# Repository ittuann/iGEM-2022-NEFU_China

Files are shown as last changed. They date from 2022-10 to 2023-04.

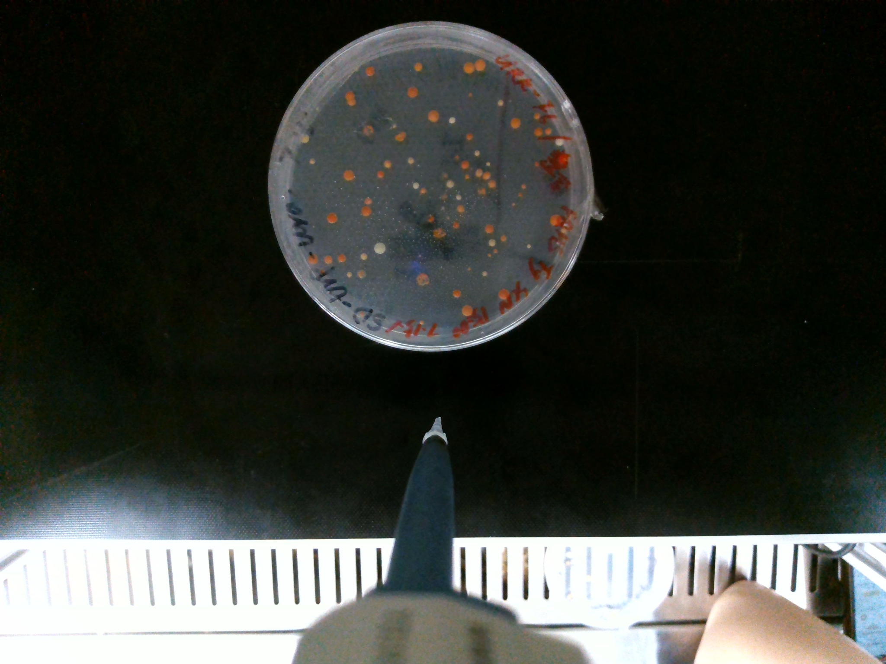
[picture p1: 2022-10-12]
Code/Visual Identification Module/10.jpg

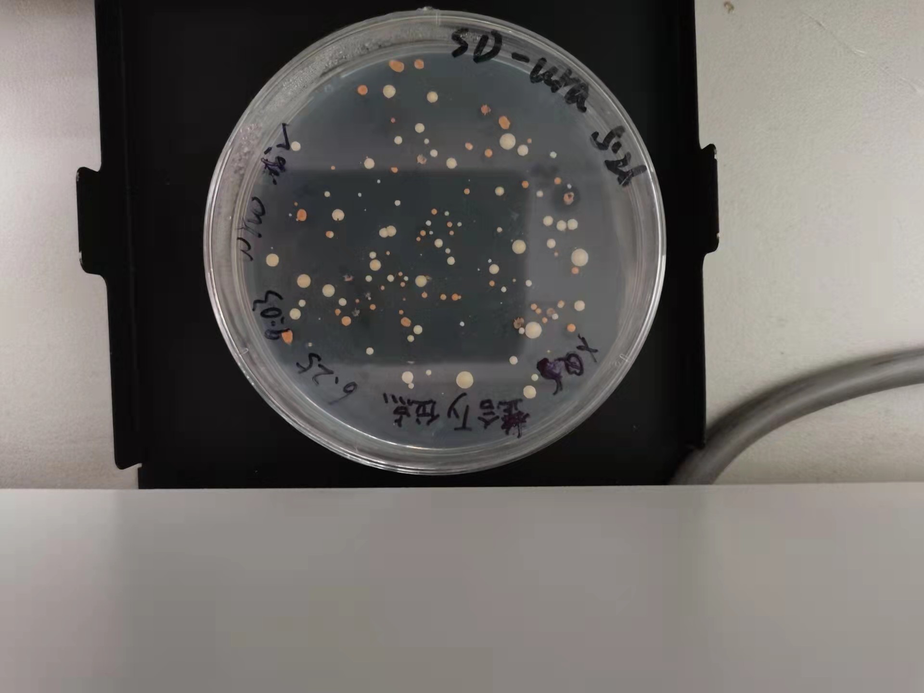
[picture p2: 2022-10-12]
Code/Visual Identification Module/1.jpg

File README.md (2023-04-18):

<div style="text-align:center;">
    <a href="https://2022.igem.wiki/nefu-china/index">
        iGEM NEFU-China
    </a>
</div>

# iGEM 2022 NEFU_China Open Project

This is iGEM team NEFU_China 2022 GitHub Repository.

Detailed information about this project can be found on our **[Wiki Website](https://2022.igem.wiki/nefu-china/hardware)**: <https://2022.igem.wiki/nefu-china/hardware>

## Repository Directory Structure

Under each folder exists a README.md document, which can be viewed for more information.

- **Code**

  Contains all project code for our four modules. (Pipette Module, Frame Module, Robotic Arm Module, Visual Identification Module)

- **Model**

  Contains all the hardware 3D models we have created (in STL format), and the complete SolidWorks project that used to create these models.

- **PCB**

  Contains two PCB projects that we designed using Altium Designer.

- **Document**

  Contains operation document for our hardware.

## License

Look at each project to find out which LICENSE it is using.

## Contacts

For any questions, feel free to contact me via email ittuann@outlook.com

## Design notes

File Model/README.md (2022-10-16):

# iGEM 2022 NEFU_China Open Project

This folder contains  all the 3D hardware models we have created (in STL format), and the complete SolidWorks project that used to create these models.

## 3D model in STL format

We have released four module independent 3D models in STL format. They are `Frame Module.STL`, `Pipette Module.STL`, `Robotic Arm Module.STL` and `Visual Identification Module.STL`.

We also released two complete 3D models of the hardware. `Hardware.STL` is the full version, `Hardware Lite.STL` is the lightweight version without the robot arm module.

The STL format is a widely used 3D model format. Most of the systems have built-in software to view the STL format. When you have downloaded the model, you can view it directly on your computer.

## Project 

We open source the entire project for designing and making 3D models. 

It requires specialized software SolidWorks 2021 to open.

With this open project, you can view every detail of our design, and modify the model as needed to use it in your work environment.

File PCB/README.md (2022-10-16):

# iGEM 2022 NEFU_China Open Project

We open source the entire project for the design and fabrication of our two PCB boards.

It requires the special software Altium Designer 2021 to open it.

With this open project, you can view every detail of our design and modify it as needed to use it in your working environment.

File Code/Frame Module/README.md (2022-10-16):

# iGEM 2022 NEFU_China Open Project

We use code from the open source project Marlin in this section. You can check this link to access that open source project https://github.com/MarlinFirmware/Marlin

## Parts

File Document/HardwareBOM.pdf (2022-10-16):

Serial number | Name | Specification | Amount | Unit price | Total cost
1 | 8mm optical shaft | 398mm，X-axis | 2 | 6.05/m | 4.92
2 | | 334mm，Y-axis | 2 | 6.05/m | 4.92
3 | | 390mm，Z-axis | 4 | 6.05/m | 9.84
4 | Extended flange linear bearings | LMF8LUU 8*15*45 | 4 | 3.16 | 12.65
5 | Longer linear bearings | LM8LUU 8*15*45 | 4 | 1.07 | 4.29
6 | Aluminium profiles (Euro 2020) | 450mm，X-axis | 4 | 1.6863/ m | 3.37
7 | | 340mm，Y-axis | 4 | 1.6863/ m | 2.53
8 | | 390mm，Z-axis | 4 | 1.6863/ m | 2.95
9 | Aluminium profiles (Euro 1010) | 467mm, hot bed | 2 | 1.602/m | 1.55
10 | Corner Code | 2020 / 2028 | 20 | 0.18 | 3.60
11 | Profile nuts | Euro 20 type M4 | 100 | 0.02 | 1.85
12 | | Euro 20 type M5 | 100 | 0.02 | 1.85

13 | Stepper motors | 2.54MM | 5 | 2.81 | 14.05
14 | Limit switches | 1A125V | 4 | 0.14 | 0.56
15 | Motor drives | A4988 | 4 | 2.53 | 10.12
16 | Heat sink | | 5 | 0.14 | 0.70
17 | T8 Screws | lead 8-350mm | 2 | 1.52 | 3.03
18 | Clearance nuts | lead 8mm | 2 | 0.98 | 1.97
19 | Stepper motor brackets | | 2 | 0.56 | 1.12
20 | Hot bed springs | | 4 | 0.11 | 0.45
21 | Nuts | | 6 | 0.06 | 0.38
22 | Limit Springs | 0.5*5*40 | 2 | 0.63 | 1.26
23 | Flexible couplings | 5×8 Flexible couplings | 2 | 0.21 | 0.42
24 | Thermistors | | 2 | 0.29 | 0.58
25 | Synchronous pulleys | 2GT 20 teeth 5mm bore and 6mm width | 2 | 1.41 | 2.81

26 | Timing belts | 2GT 6mm 2m/strip | 2 | 1.12 | 2.25
27 | Idler pulleys | Belt width 6mm 20 teeth bore 5 with teeth | 6 | 1.69 | 10.12
28 | | Belt width 6mm 20 teeth bore 5 without teeth | 2 | 1.41 | 2.81
29 | Hot bed | 200*300 | 1 | 9.55 | 9.55
30 | PE winding pipe | Inner diameter 6mm | 1 | 0.63 | 0.63
31 | Angle iron | | 12 | 0.28 | 3.37
32 | Hot bed supports | 11 gauge thickened straight sheet 40*16*2mm | 4 | 0.08 | 0.34
33 | Foot pads | 20*20*22 | 4 | 0.19 | 0.76
34 | Hexagon socket flat round head screws | M4×6 | 60 | 0.01 | 0.76
35 | | M4×8 | 12 | 0.01 | 0.17
36 | | M4×12 | 20 | 0.02 | 0.31
37 | | M4×16 | 4 | 0.02 | 0.07
38 | | M4×22 | 4 | 0.02 | 0.07
39 | | M5×8 | 40 | 0.02 | 0.84
40 | | M5×25 | 4 | 0.02 | 0.08

41 | | M5×45 | 2 | 0.04 | 0.07
42 | | M6×10 | 8 | 0.04 | 0.29
43 | Cross bolts | M2×12 | 6 | 0.01 | 0.04
44 | | M2.5×8 | 8 | 0.01 | 0.04
45 | | M3×8 | 16 | 0.01 | 0.09
46 | | M3×10 | 8 | 0.01 | 0.06
47 | | M3×14 | 44 | 0.01 | 0.37
48 | | M3×40 | 6 | 0.01 | 0.08
49 | Countersunk head screws | M3×16 | 8 | 0.01 | 0.11
50 | | M3×30 | 2 | 0.01 | 0.03
51 | Square nuts | M3*5.4*2.4 | 48 | 0.03 | 1.35
52 | Printed parts | PLA, 40% filled, 3 wall thicknesses | 1 | 7.03 | 7.03
53 | Acrylic panels | 6 large ones 7.5mm thick, 8 small ones 2mm thick | 1 | 7.87 | 7.87
54 | Touch screens | TFT24 | 1 | 19.53 | 19.53
55 | Control panels | Gen L V2.1 | 1 | 21.08 | 21.08
56 | Power supply | 12V38A | 1 | 8.15 | 8.15 | 190.093 45

1 | Visual Identification Module | 1 | 31.61 | 31.61 | 31.6125
1 | 20KG Single Shaft Servo | Brushless motors are better but more expensive | 2 | 9.13 | 18.27
2 | 35KG Single Shaft Servo | Brushless motors are better but more expensive | 1 | 12.36 | 12.36
3 | 35KG Twin Shaft Servo | Brushless motors are better but more expensive | 2 | 19.67 | 39.34
4 | Long U-bracket | | 3 | 1.48 | 4.43
5 | Short L-bracket | | 1 | 1.26 | 1.26
6 | Cup bearing | | 3 | 2.25 | 6.74
7 | Deep groove ball bearings | | 1 | 1.83 | 1.83
8 | Core plate | STM32F103C8T6 | 1 | 2.28 | 2.28
9 | Multifunctional bracket | | 4 | 1.48 | 5.90
10 | Metal rudder plate | | 5 | 2.25 | 11.24

11 | Screw nuts | 40 | 0.04 | 1.40
12 | Swivel base | 1 | 12.36 | 12.36
13 | Base counterweights | 1 | 67.44 | 67.44
14 | Base plate | 1 | 4.22 | 4.22
15 | Mechanical jaws | 1 | 11.24 | 11.24 | 200.311 25
1 | Pipette gun top cap | FDM abs 50% filled | 1 | 3.93 | 3.93
2 | Active gear for range adjustment | FDM abs 50% filled | 1 | 4.92 | 4.92
3 | Two-way cam | FDM abs 50% filled | 1 | 3.51 | 3.51
4 | 35BYJ412 motor mount | FDM abs 50% filled | 1 | 3.51 | 3.51
5 | ULN2003 stepper motor drive board | | 1 | 0.45 | 0.45
6 | 35BYJ412 motor | | 1 | 4.22 | 4.22
7 | Connection fiberglass plate | 3mm | 1 | 7.03 | 7.03
8 | Core board | STM32F103C8T6 | 1 | 2.28 | 2.28
9 | Screws | M3X22 | 2 | 0.02 | 0.04
10 | | M3X30 | 2 | 0.03 | 0.06
11 | | M3X55 | 2 | 0.03 | 0.06
12 | | M4X20 | 8 | 0.03 | 0.22

13 | M4X36 | 2 | 0.04 | 0.08 14 | Nuts | M3 | 6 | 0.01 | 0.08 15 | M4 | 10 | 0.02 | 0.21 16 | Servo connection | FDM abs 50% filled | 1 | 4.92 | 4.92 17 | Clamping piece for inner pipette gun | FDM abs 50% filled | 1 | 3.51 | 3.51 18 | Outer pipette gun clamping piece | FDM abs 50% filled | 1 | 3.51 | 3.51 19 | Inner bottom support | FDM abs 50% filled | 1 | 2.81 | 2.81 20 | Outer bottom support | FDM abs 50% filled | 1 | 2.81 | 2.81 21 | DRAGON LAB pipettes | 1 | 34.43 | 34.43 | 82.5988 Total | 504.616

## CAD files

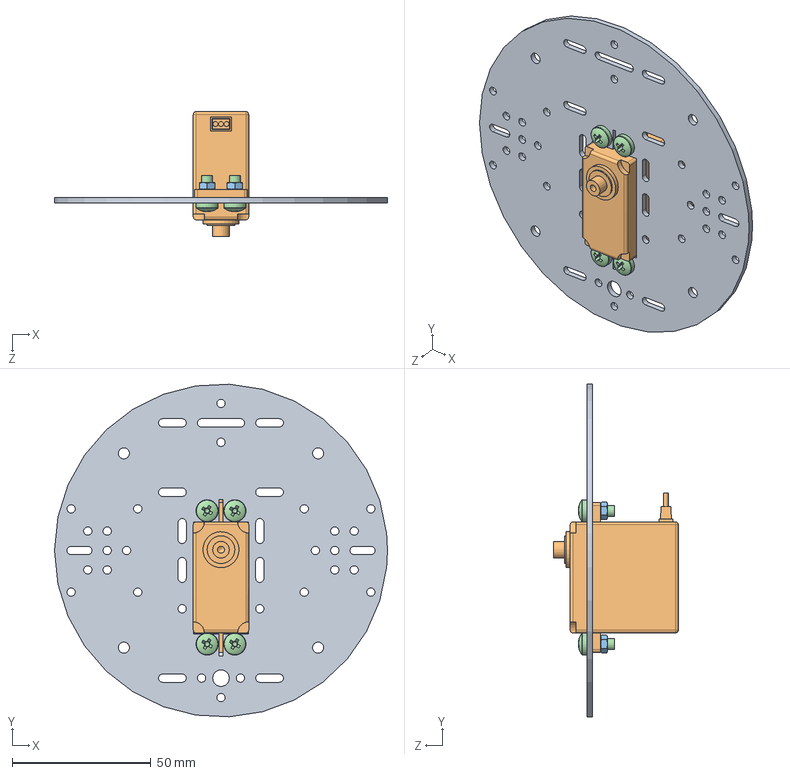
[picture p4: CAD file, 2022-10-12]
Model/Project/圆盘舵机组合.SLDASM
120.0 x 119.8 x 45.0 mm
底部圆盘
小舵机
GB6170-M4-ZN-10 x 4
GB818-M4X10-4.8 x 4

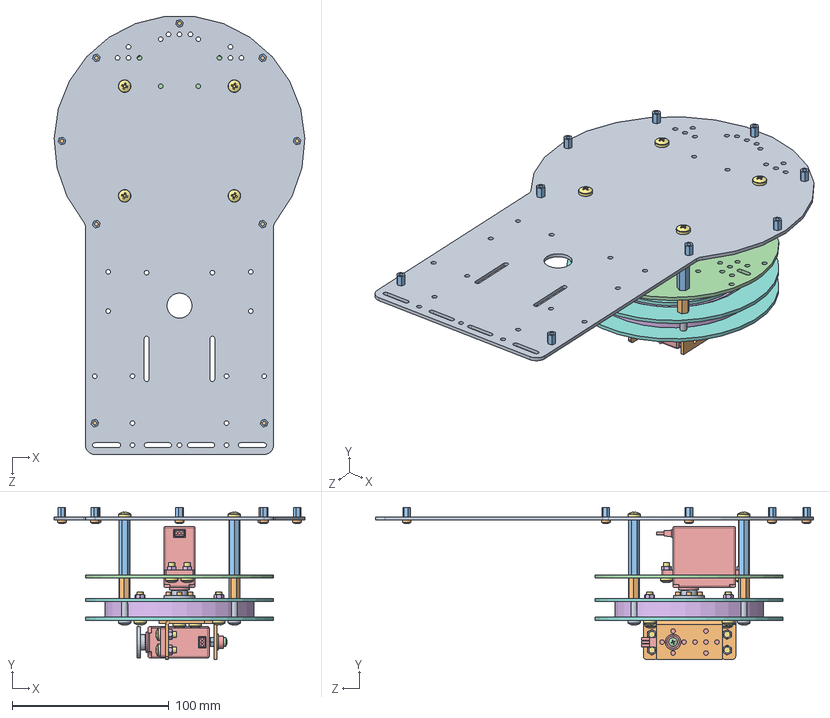
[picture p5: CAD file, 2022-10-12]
Model/Project/底座部分.SLDASM
160.0 x 97.0 x 279.4 mm
大底板
GB818-M3X6-ZN-4.8 x 13
M3X6双通铜柱 x 9
底部圆盘
小舵机 x 2
GB6170-M4-ZN-10 x 16
GB818-M4X10-4.8 x 16
小圆盘 x 2
金属舵盘 x 2
JXS006
GB6170-M3-ZN-10
GB818-M3X8-ZN-4.8
杯士轴承
大轴承
GB818-M4X18 x 4
圆环 x 2
GB818-M4X35 x 4
M4X13双通铜柱 x 4
M4X35双通铜柱 x 4

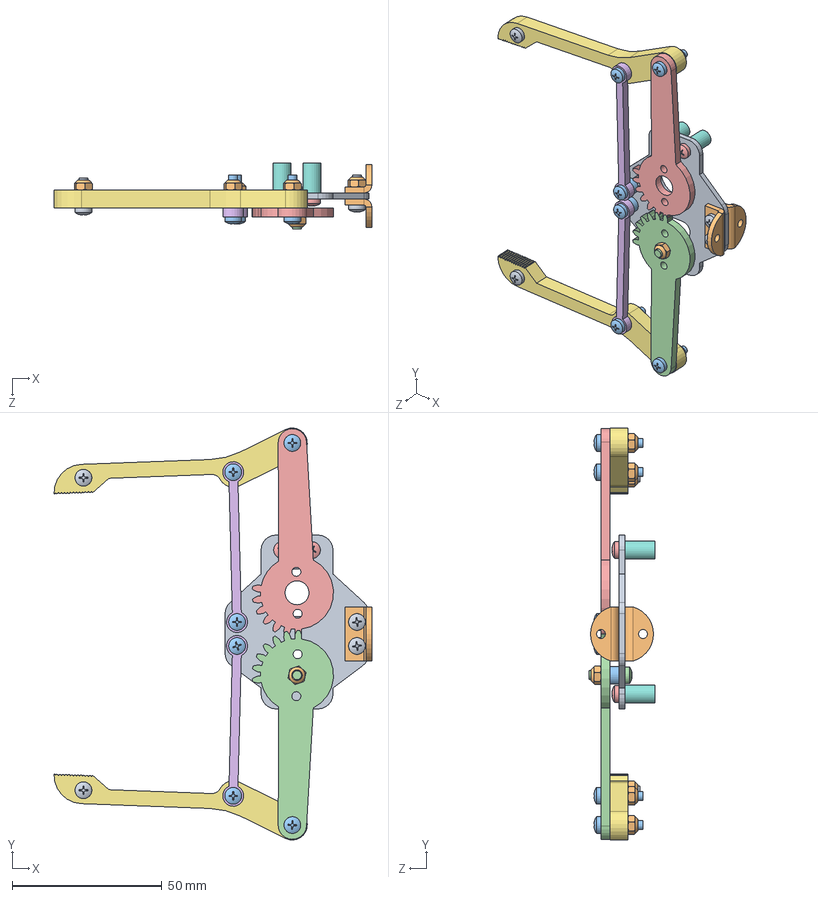
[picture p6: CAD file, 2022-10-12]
Model/Project/爪子（配合）.SLDASM
106.1 x 137.4 x 22.0 mm
手爪 （新）
安装扣 x 2
小垫片 x 3
爪子齿轮 2
爪子齿轮
小横杆 x 2
长杆 x 2
螺柱 x 4
GB818-M3X10-ZN-4.8 x 4
GB6170-M3（自锁） x 11
GB818-M3X14-ZN-4.8 x 6
GB818-M3X12-ZN-4.8
GB818-M3X6-ZN-4.8 x 4

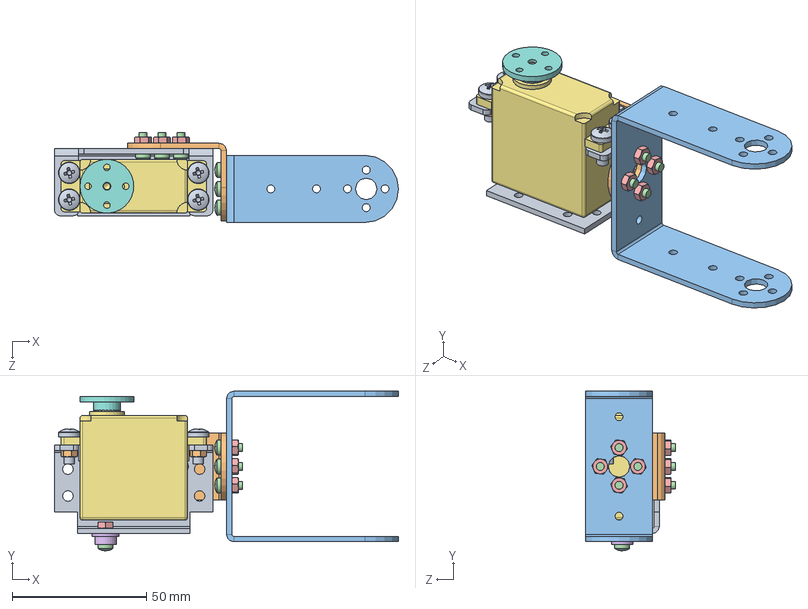
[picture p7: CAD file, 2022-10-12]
Model/Project/小臂组合（新）.SLDASM
128.0 x 59.4 x 33.5 mm
JXS006
JXS007
JXS005
GB818-M3X8-ZN-4.8 x 9
GB6170-M3-ZN-10 x 9
杯士轴承
小舵机
金属舵盘
GB818-M4X10-4.8 x 4
GB6170-M4-ZN-10 x 4

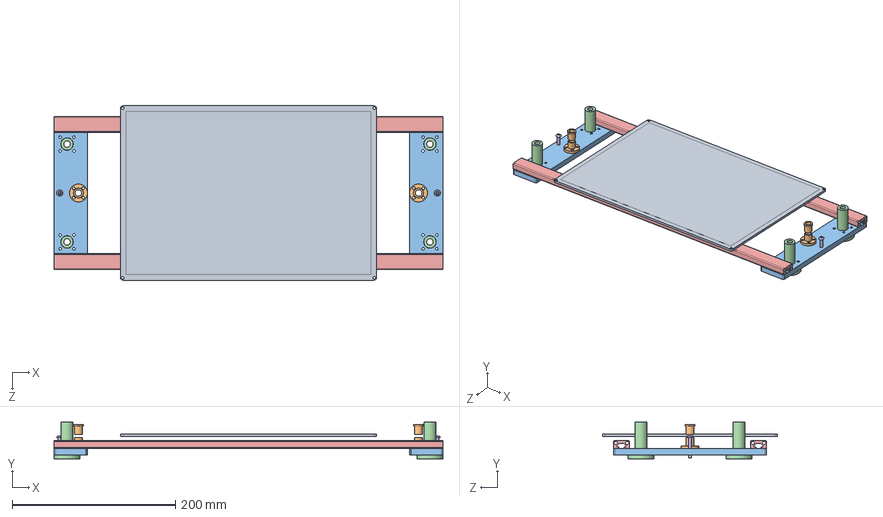
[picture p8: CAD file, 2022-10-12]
Model/Project/热床组件.SLDASM
477.0 x 45.0 x 214.0 mm
铝基板热床200×300×3
梯形螺母T8 x 2
7.5mm亚克力板 x 2
直线轴承LMF8LUU x 4
1020铝型材_热床 x 2
内六角平圆头螺钉M4×25 x 2

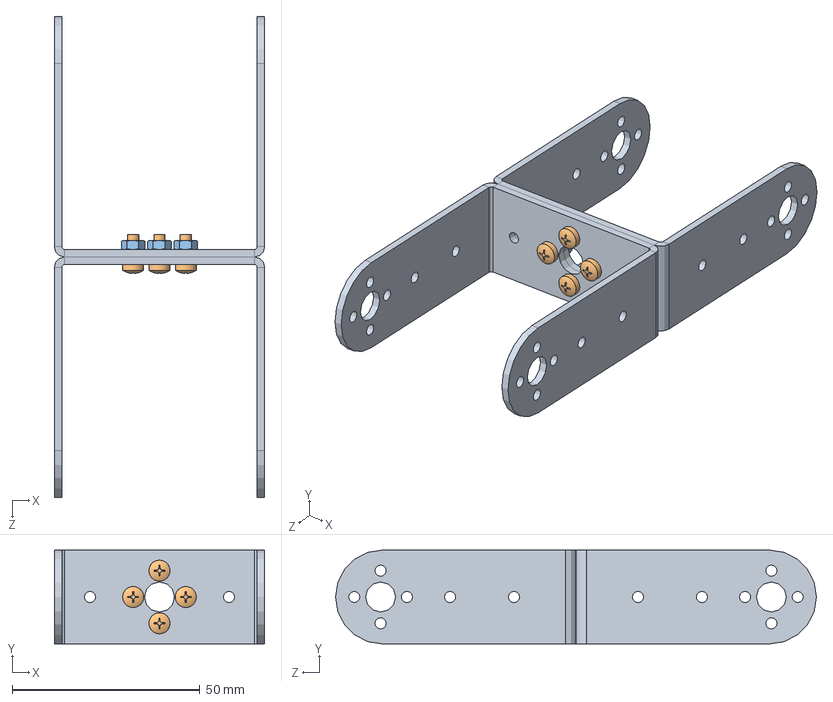
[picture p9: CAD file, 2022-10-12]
Model/Project/长臂组合.SLDASM
56.0 x 25.0 x 128.0 mm
JXS005 x 2
GB818-M3X8-ZN-4.8 x 4
GB6170-M3-ZN-10 x 4

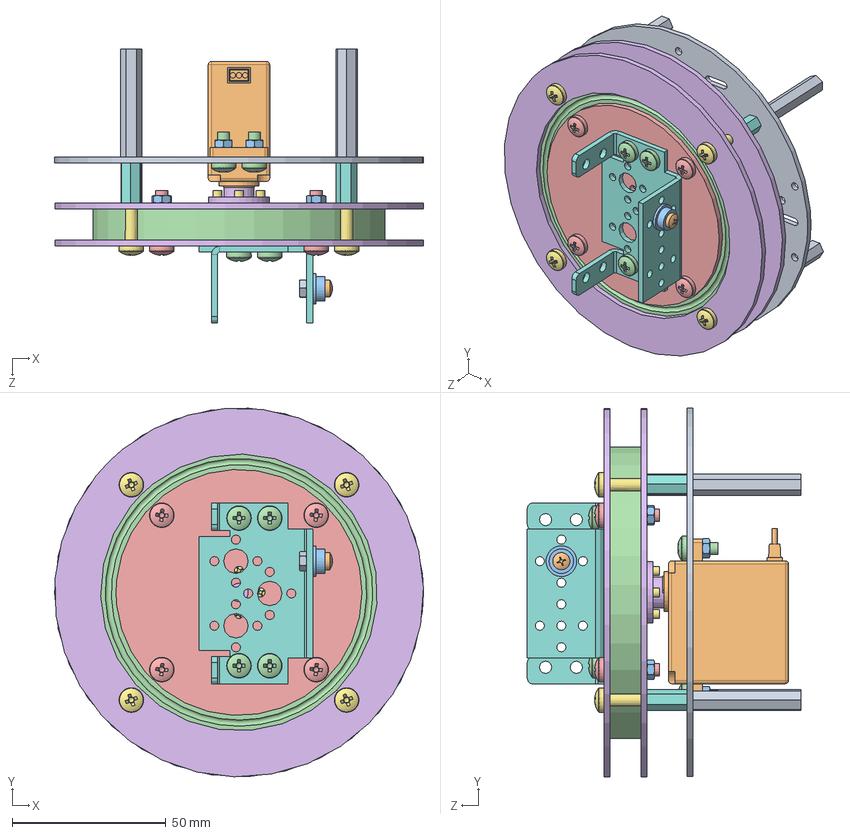
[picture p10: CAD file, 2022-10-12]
Model/Project/云台组合.SLDASM
120.0 x 119.9 x 89.0 mm
底部圆盘
小舵机
GB6170-M4-ZN-10 x 12
GB818-M4X10-4.8 x 8
小圆盘 x 2
金属舵盘
GB818-M3X6-ZN-4.8 x 4
JXS006
GB6170-M3-ZN-10
GB818-M3X8-ZN-4.8
杯士轴承
大轴承
GB818-M4X18 x 4
圆环 x 2
GB818-M4X35 x 4
M4X13双通铜柱 x 4
M4X35双通铜柱 x 4

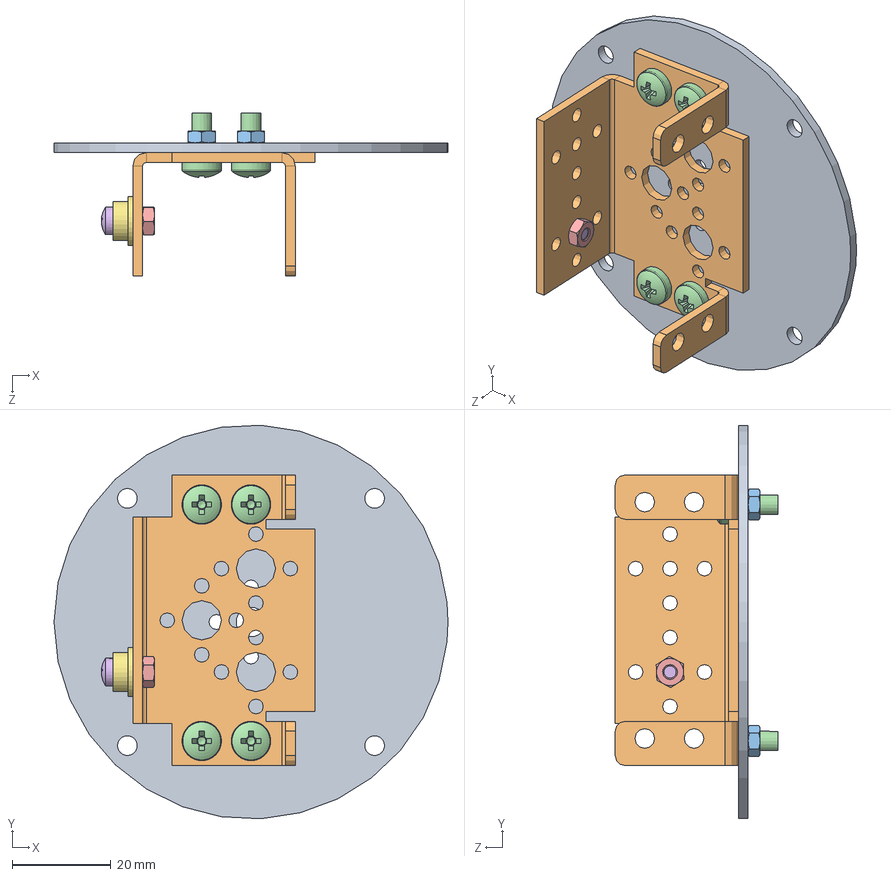
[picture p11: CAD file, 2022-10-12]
Model/Project/圆盘组合B.SLDASM
80.0 x 79.9 x 33.0 mm
小圆盘
JXS006
GB6170-M4-ZN-10 x 4
GB818-M4X10-4.8 x 4
GB6170-M3-ZN-10
GB818-M3X8-ZN-4.8
杯士轴承

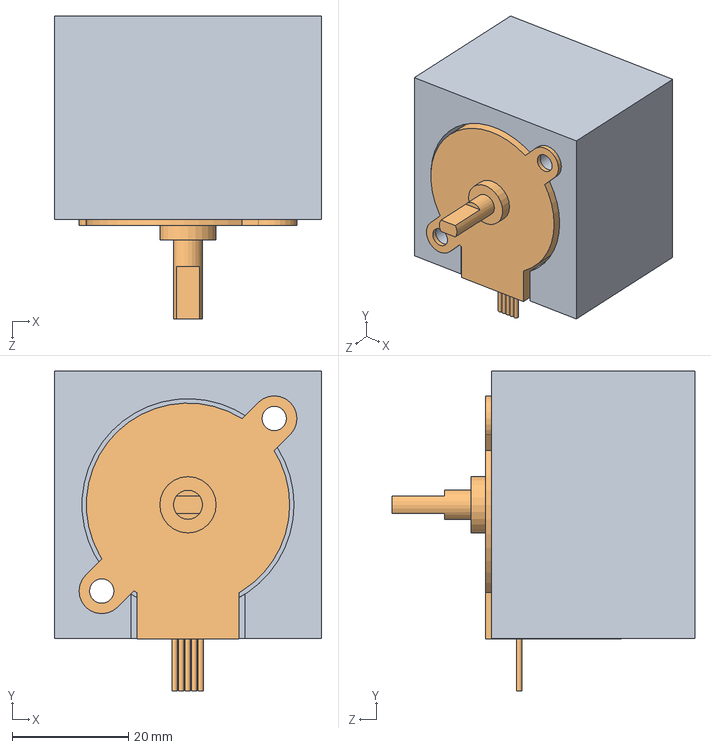
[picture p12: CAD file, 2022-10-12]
Model/Project/35BYJ配套底座.SLDASM
46.0 x 55.0 x 52.2 mm
35BYJ电机座
35BYJ412

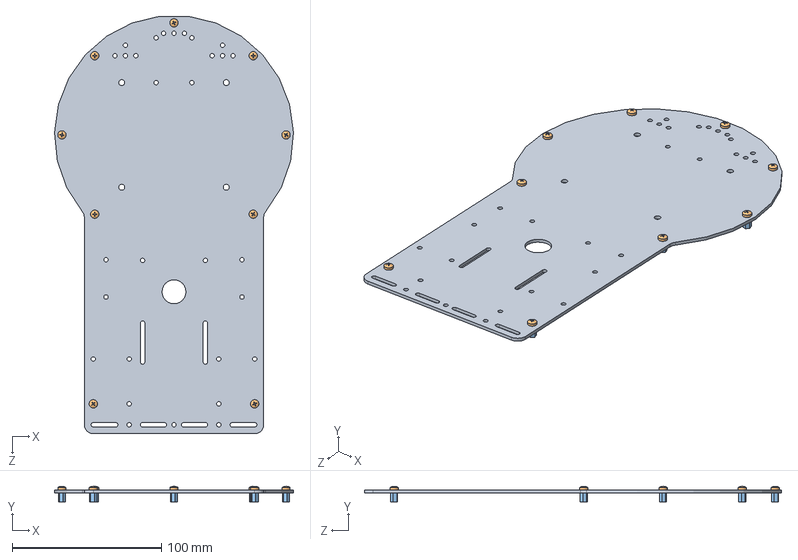
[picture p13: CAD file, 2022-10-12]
Model/Project/底板组合.SLDASM
160.0 x 10.4 x 279.4 mm
大底板
GB818-M3X6-ZN-4.8 x 9
M3X6双通铜柱 x 9

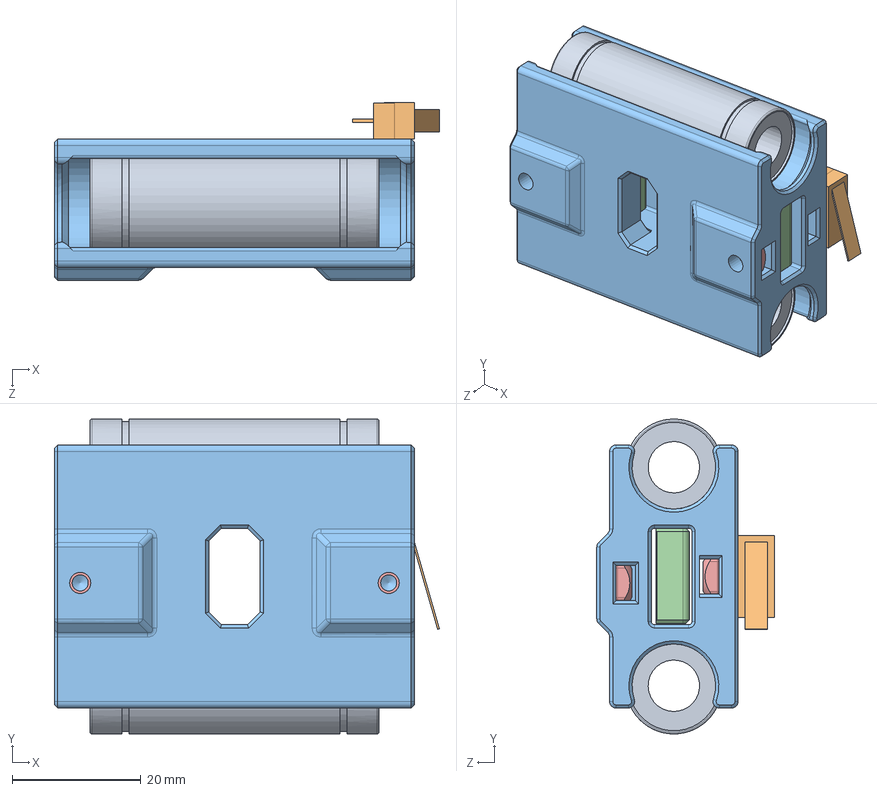
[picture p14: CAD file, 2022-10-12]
Model/Project/热端模块_E3DV6远程.SLDASM
59.9 x 49.0 x 27.6 mm
LM8LUU直线轴承8×15×45 x 2
微型限位开关1A125V
热端滑块
同步带固定片（2件） x 2
方形螺母M3 x 4

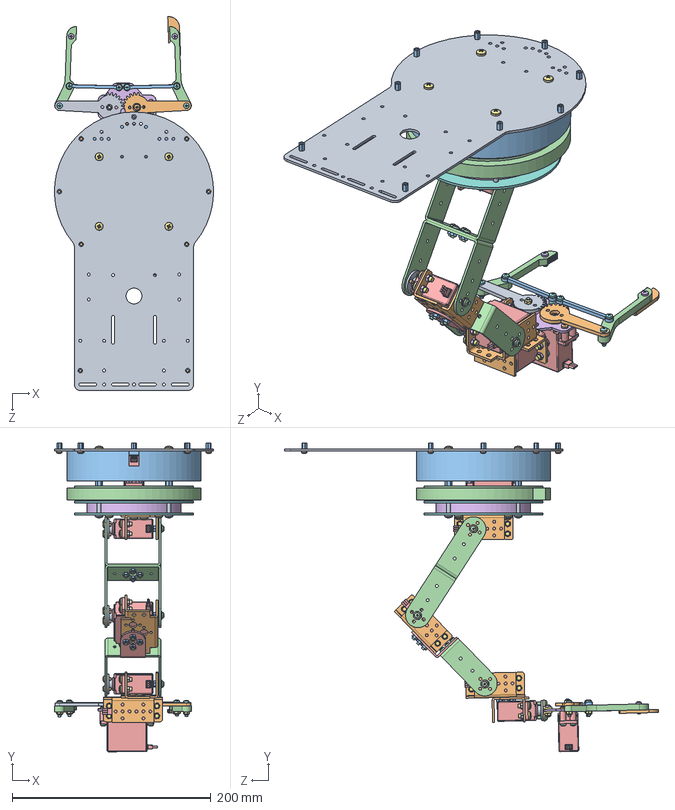
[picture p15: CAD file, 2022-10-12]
Model/Project/云台机械手套件.SLDASM
159.9 x 310.2 x 376.0 mm
大底板
GB818-M3X6-ZN-4.8 x 38
M3X6双通铜柱 x 9
底部圆盘
小舵机 x 6
GB6170-M4-ZN-10 x 28
GB818-M4X10-4.8 x 28
小圆盘 x 2
金属舵盘 x 5
JXS006 x 4
GB6170-M3-ZN-10 x 19
GB818-M3X8-ZN-4.8 x 21
杯士轴承 x 3
大轴承
GB818-M4X18 x 4
圆环 x 2
GB818-M4X35 x 4
M4X13双通铜柱 x 4
M4X35双通铜柱 x 4
JXS005 x 3
JXS007
手爪 （新）
安装扣 x 2
小垫片 x 3
爪子齿轮 2
爪子齿轮
小横杆 x 2
长杆 x 2
螺柱 x 4
GB818-M3X10-ZN-4.8 x 4
GB6170-M3（自锁） x 11
GB818-M3X14-ZN-4.8 x 6
GB818-M3X12-ZN-4.8
中心配重块
中心配重块上层

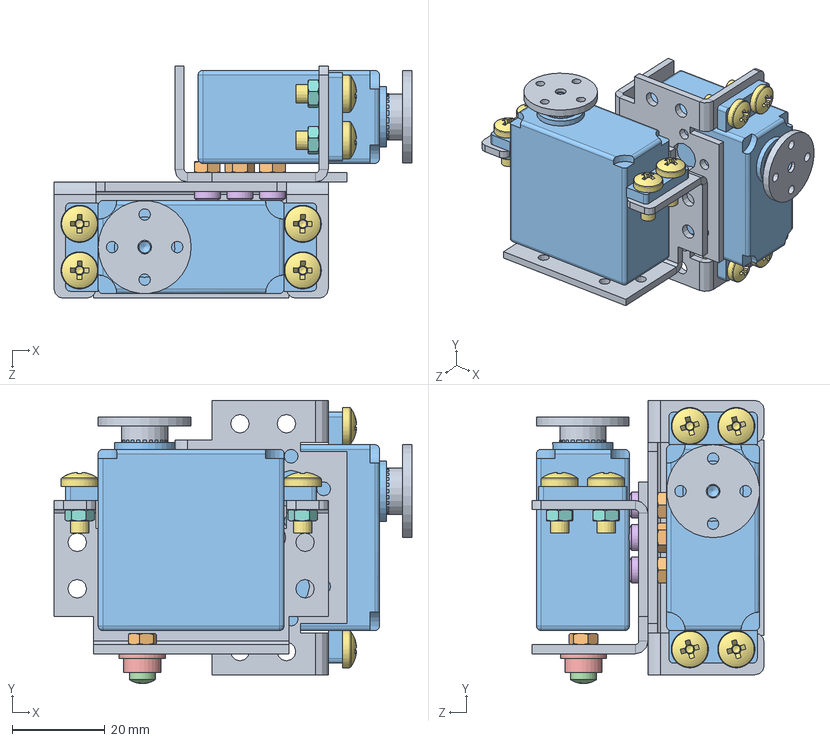
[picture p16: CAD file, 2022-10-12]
Model/Project/手腕组合（新）.SLDASM
77.0 x 60.9 x 50.0 mm
JXS006 x 2
GB6170-M3-ZN-10 x 5
小舵机 x 2
GB818-M3X8-ZN-4.8
杯士轴承
GB818-M3X6-ZN-4.8 x 4
GB818-M4X10-4.8 x 8
GB6170-M4-ZN-10 x 8
金属舵盘 x 2

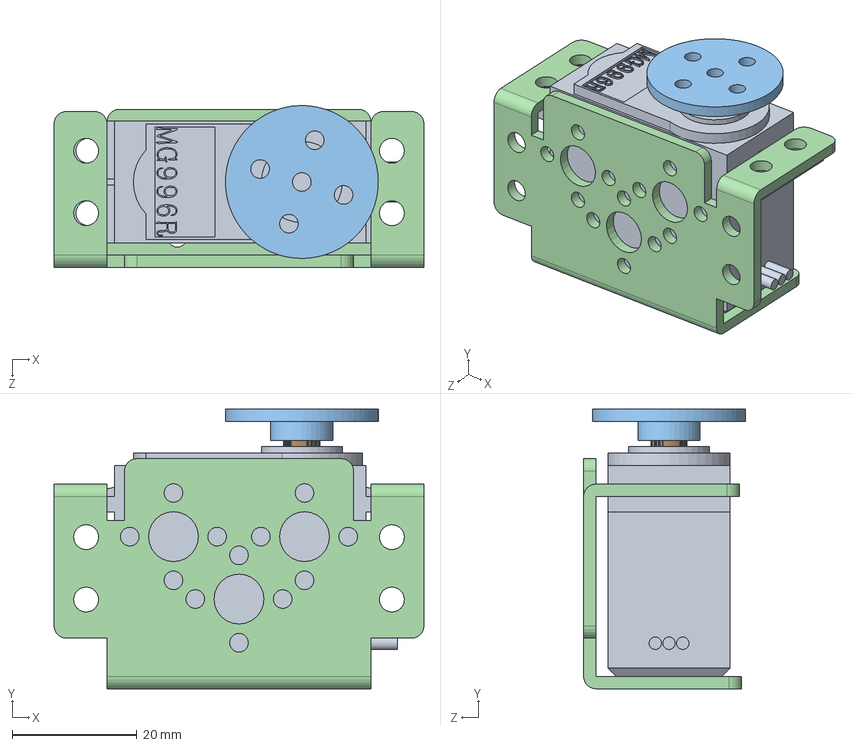
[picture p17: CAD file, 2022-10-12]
Model/Project/舵机.SLDASM
59.3 x 44.8 x 25.9 mm
舵机外壳
舵机轴
舵盘
221-BB-02-49 舵机座

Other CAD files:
Model/Project/Дозатор пипеточный одноканальный.SLDASM
Model/Project/Z轴组件-1.SLDASM
Model/Project/Y组件.SLDASM
Model/Project/Z轴组件.SLDASM
Model/Pipette Module.STL
Model/Project/1020铝型材_热床.SLDPRT
Model/Project/1925联轴器8×5.SLDPRT
Model/Project/2020铝型材_X轴.SLDPRT
Model/Project/2020铝型材_Y轴.SLDPRT
Model/Project/2020铝型材_Z轴.SLDPRT
Model/Project/221-BB-02-49 舵机座.SLDPRT
Model/Project/35BYJ412.SLDPRT
Model/Project/35BYJ电机座.SLDPRT
Model/Project/42步进电机.SLDPRT
Model/Project/42步进电机支架_铝合金.SLDPRT
Model/Project/5MM同步轮.SLDPRT
Model/Project/5MM惰轮.SLDPRT
Model/Project/5MM惰轮_无齿.SLDPRT
Model/Project/7.5mm亚克力板.SLDPRT
Model/Project/8mm光轴_X轴408mm.SLDPRT
Model/Project/8mm光轴_Y轴340mm.SLDPRT
Model/Project/8mm光轴_Z轴.SLDPRT
Model/Project/GB818-M3X10-ZN-4.8.SLDPRT
Model/Project/GB818-M3X12-ZN-4.8.SLDPRT
Model/Project/GB818-M3X14-ZN-4.8.SLDPRT
Model/Project/GB818-M3X6-ZN-4.8.SLDPRT
Model/Project/GB818-M3X8-ZN-4.8.SLDPRT
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

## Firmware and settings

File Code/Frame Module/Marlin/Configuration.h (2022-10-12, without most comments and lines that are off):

#pragma once
#define CONFIGURATION_H_VERSION 02000902
#define STRING_CONFIG_H_AUTHOR "(none, default config)" // Who made the changes.
#define SHOW_BOOTSCREEN
#define SERIAL_PORT 0
#define BAUDRATE 115200
  #define MOTHERBOARD BOARD_MKS_GEN_L_V21
#if LINEAR_AXES >= 4
  #define AXIS4_NAME 'A' // :['A', 'B', 'C', 'U', 'V', 'W']
#endif
#if LINEAR_AXES >= 5
  #define AXIS5_NAME 'B' // :['A', 'B', 'C', 'U', 'V', 'W']
#endif
#if LINEAR_AXES >= 6
  #define AXIS6_NAME 'C' // :['A', 'B', 'C', 'U', 'V', 'W']
#endif
#define EXTRUDERS 1
#define DEFAULT_NOMINAL_FILAMENT_DIA 1.75
#define TEMP_SENSOR_0 1
#define TEMP_SENSOR_1 0
#define TEMP_SENSOR_2 0
#define TEMP_SENSOR_3 0
#define TEMP_SENSOR_4 0
#define TEMP_SENSOR_5 0
#define TEMP_SENSOR_6 0
#define TEMP_SENSOR_7 0
#define TEMP_SENSOR_BED 1
#define TEMP_SENSOR_PROBE 0
#define TEMP_SENSOR_CHAMBER 0
#define TEMP_SENSOR_COOLER 0
#define TEMP_SENSOR_BOARD 0
#define TEMP_SENSOR_REDUNDANT 0
#define DUMMY_THERMISTOR_998_VALUE  25
#define DUMMY_THERMISTOR_999_VALUE 100
#define TEMP_RESIDENCY_TIME         10  // (seconds) Time to wait for hotend to "settle" in M109
#define TEMP_WINDOW                  1  // (°C) Temperature proximity for the "temperature reached" timer
#define TEMP_HYSTERESIS              3  // (°C) Temperature proximity considered "close enough" to the target
#define TEMP_BED_RESIDENCY_TIME     10  // (seconds) Time to wait for bed to "settle" in M190
#define TEMP_BED_WINDOW              1  // (°C) Temperature proximity for the "temperature reached" timer
#define TEMP_BED_HYSTERESIS          3  // (°C) Temperature proximity considered "close enough" to the target
#define TEMP_CHAMBER_RESIDENCY_TIME 10  // (seconds) Time to wait for chamber to "settle" in M191
#define TEMP_CHAMBER_WINDOW          1  // (°C) Temperature proximity for the "temperature reached" timer
#define TEMP_CHAMBER_HYSTERESIS      3  // (°C) Temperature proximity considered "close enough" to the target
#if TEMP_SENSOR_REDUNDANT
  #define TEMP_SENSOR_REDUNDANT_SOURCE    E1  // The sensor that will provide the redundant reading.
  #define TEMP_SENSOR_REDUNDANT_TARGET    E0  // The sensor that we are providing a redundant reading for.
  #define TEMP_SENSOR_REDUNDANT_MAX_DIFF  10  // (°C) Temperature difference that will trigger a print abort.
#endif
#define HEATER_0_MINTEMP   5
#define HEATER_1_MINTEMP   5
#define HEATER_2_MINTEMP   5
#define HEATER_3_MINTEMP   5
#define HEATER_4_MINTEMP   5
#define HEATER_5_MINTEMP   5
#define HEATER_6_MINTEMP   5
#define HEATER_7_MINTEMP   5
#define BED_MINTEMP        5
#define CHAMBER_MINTEMP    5
#define HEATER_0_MAXTEMP 275
#define HEATER_1_MAXTEMP 275
#define HEATER_2_MAXTEMP 275
#define HEATER_3_MAXTEMP 275
#define HEATER_4_MAXTEMP 275
#define HEATER_5_MAXTEMP 275
#define HEATER_6_MAXTEMP 275
#define HEATER_7_MAXTEMP 275
#define BED_MAXTEMP      150
#define CHAMBER_MAXTEMP  60
#define HOTEND_OVERSHOOT 15   // (°C) Forbid temperatures over MAXTEMP - OVERSHOOT
#define BED_OVERSHOOT    10   // (°C) Forbid temperatures over MAXTEMP - OVERSHOOT
#define COOLER_OVERSHOOT  2   // (°C) Forbid temperatures closer than OVERSHOOT
#define PIDTEMP
#define BANG_MAX 255     // Limits current to nozzle while in bang-bang mode; 255=full current
#define PID_MAX BANG_MAX // Limits current to nozzle while PID is active (see PID_FUNCTIONAL_RANGE below); 255=full current
#define PID_K1 0.95      // Smoothing factor within any PID loop
    #define DEFAULT_Kp  19.02
    #define DEFAULT_Ki  1.07
    #define DEFAULT_Kd  84.13
#define MAX_BED_POWER 255 // limits duty cycle to bed; 255=full current
#define MAX_CHAMBER_POWER 255 // limits duty cycle to chamber heater; 255=full current
  #define PID_FUNCTIONAL_RANGE 10 // If the temperature difference between the target temperature and the actual temperature
#define PREVENT_COLD_EXTRUSION
#define EXTRUDE_MINTEMP 170
#define PREVENT_LENGTHY_EXTRUDE
#define EXTRUDE_MAXLENGTH 200
#define THERMAL_PROTECTION_HOTENDS // Enable thermal protection for all extruders
#define THERMAL_PROTECTION_BED     // Enable thermal protection for the heated bed
#define THERMAL_PROTECTION_CHAMBER // Enable thermal protection for the heated chamber
#define THERMAL_PROTECTION_COOLER  // Enable thermal protection for the laser cooling
#define COREXY
#define USE_XMIN_PLUG
#define USE_YMIN_PLUG
#define USE_ZMIN_PLUG
#define USE_XMAX_PLUG
#define ENDSTOPPULLUPS
#define X_MIN_ENDSTOP_INVERTING true // Set to true to invert the logic of the endstop.
#define Y_MIN_ENDSTOP_INVERTING true // Set to true to invert the logic of the endstop.
#define Z_MIN_ENDSTOP_INVERTING true // Set to true to invert the logic of the endstop.
#define I_MIN_ENDSTOP_INVERTING false // Set to true to invert the logic of the endstop.
#define J_MIN_ENDSTOP_INVERTING false // Set to true to invert the logic of the endstop.
#define K_MIN_ENDSTOP_INVERTING false // Set to true to invert the logic of the endstop.
#define X_MAX_ENDSTOP_INVERTING true // Set to true to invert the logic of the endstop.
#define Y_MAX_ENDSTOP_INVERTING false // Set to true to invert the logic of the endstop.
#define Z_MAX_ENDSTOP_INVERTING false // Set to true to invert the logic of the endstop.
#define I_MAX_ENDSTOP_INVERTING false // Set to true to invert the logic of the endstop.
#define J_MAX_ENDSTOP_INVERTING false // Set to true to invert the logic of the endstop.
#define K_MAX_ENDSTOP_INVERTING false // Set to true to invert the logic of the endstop.
#define Z_MIN_PROBE_ENDSTOP_INVERTING false // Set to true to invert the logic of the probe.
#define X_DRIVER_TYPE  TMC2209
#define Y_DRIVER_TYPE  TMC2209
#define Z_DRIVER_TYPE  TMC2209
#define Z2_DRIVER_TYPE TMC2209
#define E0_DRIVER_TYPE TMC2209
#define DEFAULT_AXIS_STEPS_PER_UNIT   { 80, 80, 400, 386 }
#define DEFAULT_MAX_FEEDRATE          { 500, 500 , 3, 100 }
#define DEFAULT_MAX_ACCELERATION      { 3000, 3000, 100, 10000 }
#define DEFAULT_ACCELERATION          3000    // X, Y, Z and E acceleration for printing moves
#define DEFAULT_RETRACT_ACCELERATION  3000    // E acceleration for retracts
#define DEFAULT_TRAVEL_ACCELERATION   3000    // X, Y, Z acceleration for travel (non printing) moves
#define DEFAULT_EJERK    5.0  // May be used by Linear Advance
  #define JUNCTION_DEVIATION_MM 0.013 // (mm) Distance from real junction edge
  #define JD_HANDLE_SMALL_SEGMENTS    // Use curvature estimation instead of just the junction angle
#define Z_MIN_PROBE_USES_Z_MIN_ENDSTOP_PIN
#define NOZZLE_TO_PROBE_OFFSET { 10, 10, 0 }
#define PROBING_MARGIN 10
#define XY_PROBE_FEEDRATE (133*60)
#define Z_PROBE_FEEDRATE_FAST (4*60)
#define Z_PROBE_FEEDRATE_SLOW (Z_PROBE_FEEDRATE_FAST / 2)
#define Z_CLEARANCE_DEPLOY_PROBE   10 // Z Clearance for Deploy/Stow
#define Z_CLEARANCE_BETWEEN_PROBES  5 // Z Clearance between probe points
#define Z_CLEARANCE_MULTI_PROBE     5 // Z Clearance between multiple probes
#define Z_PROBE_LOW_POINT          -2 // Farthest distance below the trigger-point to go before stopping
#define Z_PROBE_OFFSET_RANGE_MIN -20
#define Z_PROBE_OFFSET_RANGE_MAX 20
#define X_ENABLE_ON 0
#define Y_ENABLE_ON 0
#define Z_ENABLE_ON 0
#define E_ENABLE_ON 0 // For all extruders
#define DISABLE_X false
#define DISABLE_Y false
#define DISABLE_Z false
#define DISABLE_E false             // Disable the extruder when not stepping
#define DISABLE_INACTIVE_EXTRUDER   // Keep only the active extruder enabled
#define INVERT_X_DIR true
#define INVERT_Y_DIR true
#define INVERT_Z_DIR false
#define INVERT_E0_DIR false
#define INVERT_E1_DIR false
#define INVERT_E2_DIR false
#define INVERT_E3_DIR false
#define INVERT_E4_DIR false
#define INVERT_E5_DIR false
#define INVERT_E6_DIR false
#define INVERT_E7_DIR false
#define X_HOME_DIR -1
#define Y_HOME_DIR -1
#define Z_HOME_DIR -1
#define X_BED_SIZE 300
#define Y_BED_SIZE 200
#define X_MIN_POS 0
#define Y_MIN_POS 0
#define Z_MIN_POS 0
#define X_MAX_POS X_BED_SIZE
#define Y_MAX_POS Y_BED_SIZE
#define Z_MAX_POS 260
#define MIN_SOFTWARE_ENDSTOPS
  #define MIN_SOFTWARE_ENDSTOP_X
  #define MIN_SOFTWARE_ENDSTOP_Y
  #define MIN_SOFTWARE_ENDSTOP_Z
  #define MIN_SOFTWARE_ENDSTOP_I
  #define MIN_SOFTWARE_ENDSTOP_J
  #define MIN_SOFTWARE_ENDSTOP_K
#define MAX_SOFTWARE_ENDSTOPS
  #define MAX_SOFTWARE_ENDSTOP_X
  #define MAX_SOFTWARE_ENDSTOP_Y
  #define MAX_SOFTWARE_ENDSTOP_Z
  #define MAX_SOFTWARE_ENDSTOP_I
  #define MAX_SOFTWARE_ENDSTOP_J
  #define MAX_SOFTWARE_ENDSTOP_K
#define HOMING_FEEDRATE_MM_M { (50*60), (50*60), (4*60) }
#define VALIDATE_HOMING_ENDSTOPS
#define EEPROM_SETTINGS     // Persistent storage with M500 and M501
#define EEPROM_CHITCHAT       // Give feedback on EEPROM commands. Disable to save PROGMEM.
#define EEPROM_BOOT_SILENT    // Keep M503 quiet and only give errors during first load
#define HOST_KEEPALIVE_FEATURE        // Disable this if your host doesn't like keepalive messages
#define DEFAULT_KEEPALIVE_INTERVAL 2  // Number of seconds between "busy" messages. Set with M113.
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

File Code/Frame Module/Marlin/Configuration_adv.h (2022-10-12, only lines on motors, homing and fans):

#define E0_AUTO_FAN_PIN -1
#define E1_AUTO_FAN_PIN -1
#define E2_AUTO_FAN_PIN -1
#define E3_AUTO_FAN_PIN -1
#define E4_AUTO_FAN_PIN -1
#define E5_AUTO_FAN_PIN -1
#define E6_AUTO_FAN_PIN -1
#define E7_AUTO_FAN_PIN -1
#define CHAMBER_AUTO_FAN_PIN -1
#define COOLER_AUTO_FAN_PIN -1
#define COOLER_FAN_PIN -1
#define HOMING_BUMP_MM      { 5, 5, 2 }       // (mm) Backoff from endstops after first bump
#define HOMING_BUMP_DIVISOR { 2, 2, 4 }       // Re-Bump Speed Divisor (Divides the Homing Feedrate)
#define MICROSTEP_MODES { 16, 16, 16, 16, 16, 16 } // [1,2,4,8,16]
    #define X_CURRENT       800        // (mA) RMS current. Multiply by 1.414 for peak current.
    #define X_CURRENT_HOME  X_CURRENT  // (mA) RMS current for sensorless homing
    #define X_MICROSTEPS     16        // 0..256
    #define Y_CURRENT       800
    #define Y_CURRENT_HOME  Y_CURRENT
    #define Y_MICROSTEPS     16
    #define Z_CURRENT       800
    #define Z_CURRENT_HOME  Z_CURRENT
    #define Z_MICROSTEPS     16
    #define Z2_CURRENT      800
    #define Z2_CURRENT_HOME Z2_CURRENT
    #define Z2_MICROSTEPS    Z_MICROSTEPS
    #define E0_CURRENT      800
    #define E0_MICROSTEPS    16
  #define X_HYBRID_THRESHOLD     100  // [mm/s]
  #define X2_HYBRID_THRESHOLD    100
  #define Y_HYBRID_THRESHOLD     100
  #define Y2_HYBRID_THRESHOLD    100
  #define Z_HYBRID_THRESHOLD       3
  #define Z2_HYBRID_THRESHOLD      3
  #define Z3_HYBRID_THRESHOLD      3
  #define Z4_HYBRID_THRESHOLD      3
  #define I_HYBRID_THRESHOLD       3
  #define J_HYBRID_THRESHOLD       3
  #define K_HYBRID_THRESHOLD       3
  #define E0_HYBRID_THRESHOLD     30
  #define E1_HYBRID_THRESHOLD     30
  #define E2_HYBRID_THRESHOLD     30
  #define E3_HYBRID_THRESHOLD     30
  #define E4_HYBRID_THRESHOLD     30
  #define E5_HYBRID_THRESHOLD     30
  #define E6_HYBRID_THRESHOLD     30
  #define E7_HYBRID_THRESHOLD     30

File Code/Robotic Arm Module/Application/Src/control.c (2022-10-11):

/*
 *  control.c
 *
 *  Created on: 2022年04月14日
 *      Author: LBQ
 */

#include "control.h"

extern TIM_HandleTypeDef htim2;
extern TIM_HandleTypeDef htim3;
extern TIM_HandleTypeDef htim4;
extern UART_HandleTypeDef huart2;

#define SERVO_NUM 6
#define ActionGroups1_NodesNum 7		// 动作组1号的节点数

uint8_t NodesNum = 0;					// 当前动作节点序号
float AngleSetp[SERVO_NUM] = {0};		// 暂存每个舵机每步应转角度
uint16_t AnglCont[SERVO_NUM] = {0};		// 暂存每个舵机步数
bool_t ServoFlag[SERVO_NUM] = {0};		// 暂存每个舵机是否完成转动标志位
uint8_t receive_data = 0;

// 设置角度 设置转动到指定角度所需时间
float ActionGroups1[ActionGroups1_NodesNum][SERVO_NUM][2] = {
	{{10.0f, 0}, {10.0f, 0}, {10.0f, 0}, {10.0f, 0}, {10.0f, 0}, {10.0f, 0}},				// 初始值
	{{20.0f, 1000}, {10.0f, 100}, {10.0f, 100}, {10.0f, 100}, {10.0f, 100}, {10.0f, 100}},	// 节点1
	{{30.0f, 1000}, {10.0f, 100}, {10.0f, 100}, {10.0f, 100}, {10.0f, 100}, {10.0f, 100}},
	{{40.0f, 1000}, {10.0f, 100}, {10.0f, 100}, {10.0f, 100}, {10.0f, 100}, {10.0f, 100}},
	{{50.0f, 1000}, {10.0f, 100}, {10.0f, 100}, {10.0f, 100}, {10.0f, 100}, {10.0f, 100}},
	{{60.0f, 1000}, {10.0f, 100}, {10.0f, 100}, {10.0f, 100}, {10.0f, 100}, {10.0f, 100}},
	{{70.0f, 1000}, {10.0f, 100}, {10.0f, 100}, {10.0f, 100}, {10.0f, 100}, {10.0f, 100}}
};	// 动作组1号
float TestGroups[SERVO_NUM] = {50.0f, 60.0f, 70.0f, 80.0f, 90.0f, 100.0f};	// 调试单个角度用

// 函数声明
void ServoPWM_Init(void);
void SetServoAngle2PWM(float angle, uint8_t servonum);

void HAL_UART_RxCpltCallback(UART_HandleTypeDef *huart)
{
	if (huart == &huart2)
	{
		HAL_UART_Receive_IT(&huart2, &receive_data, 1);

		if (receive_data == 49) {
			
		} else if (receive_data == 50) {
			
		} else if (receive_data == 51) {
			
		}
	}
}

void StartDefaultTask(void const * argument)
{
  for(;;)
  {
	  HAL_GPIO_TogglePin(LED_GPIO_Port, LED_Pin);
	  osDelay(500);
  }
}

void ControlTaskFunction(void const * argument)
{
	portTickType xLastWakeTime;
	const uint16_t TaskTim = 50;
	const portTickType xFrequency = pdMS_TO_TICKS(TaskTim);	// 绝对延时

	ServoPWM_Init();

	// 用当前tick时间初始化 pxPreviousWakeTime
	xLastWakeTime = xTaskGetTickCount();

	while (1)
	{
		// 任务绝对延时
		vTaskDelayUntil(&xLastWakeTime, xFrequency);

		if (NodesNum < ActionGroups1_NodesNum && NodesNum)
		{
			for (uint8_t s = 0; s < SERVO_NUM; s ++ )
			{
				AngleSetp[s] = ActionGroups1[NodesNum - 1][s][0] + (ActionGroups1[NodesNum][s][0] - ActionGroups1[NodesNum - 1][s][0]) * AnglCont[s] * TaskTim / ActionGroups1[NodesNum][s][1];
				SetServoAngle2PWM(AngleSetp[s], s);
				
				// 判断是否已转完指定角度
				if (AnglCont[s] < (uint16_t)(ActionGroups1[NodesNum][s][1]) / TaskTim) {
					AnglCont[s] ++ ;
				} else {
					ServoFlag[s] = 1;
				}
			}
		}
		
		if (!NodesNum)
		{
			for (uint8_t s = 0; s < SERVO_NUM; s ++ )
			{
				SetServoAngle2PWM(ActionGroups1[NodesNum][s][0], s);
			}
			NodesNum ++ ;
		}

		if (ServoFlag[0] && ServoFlag[1] && ServoFlag[2] && ServoFlag[3] && ServoFlag[4] && ServoFlag[5])
		{
			memset(AngleSetp, 0, sizeof(AngleSetp));
			memset(AnglCont, 0, sizeof(AnglCont));
			memset(ServoFlag, 0, sizeof(ServoFlag));
			NodesNum ++ ;										// 单次执行动作组
//			NodesNum = (NodesNum + 1) % ActionGroups1_NodesNum;	// 循环执行动作组
		}
		
		// 调试单个角度用
//		for (uint8_t s = 0; s < SERVO_NUM; s ++ )
//		{
//			SetServoAngle2PWM(TestGroups[s], s);
//		}
		
	}
}

// 函数定义
void ServoPWM_Init(void)
{
	uint16_t InitialValue = 500;
	HAL_TIM_Base_Start(&Servo1_TIM);
	HAL_TIM_Base_Start(&Servo2_TIM);
	HAL_TIM_Base_Start(&Servo3_TIM);
	HAL_TIM_Base_Start(&Servo4_TIM);
	HAL_TIM_Base_Start(&Servo5_TIM);
	HAL_TIM_Base_Start(&Servo6_TIM);
	HAL_TIM_PWM_Start(&Servo1_TIM, Servo1_Channel);
	HAL_TIM_PWM_Start(&Servo2_TIM, Servo2_Channel);
	HAL_TIM_PWM_Start(&Servo3_TIM, Servo3_Channel);
	HAL_TIM_PWM_Start(&Servo4_TIM, Servo4_Channel);
	HAL_TIM_PWM_Start(&Servo5_TIM, Servo5_Channel);
	HAL_TIM_PWM_Start(&Servo6_TIM, Servo6_Channel);
	__HAL_TIM_SetCompare(&Servo1_TIM, Servo1_Channel, InitialValue);
	__HAL_TIM_SetCompare(&Servo2_TIM, Servo2_Channel, InitialValue);
	__HAL_TIM_SetCompare(&Servo3_TIM, Servo3_Channel, InitialValue);
	__HAL_TIM_SetCompare(&Servo4_TIM, Servo4_Channel, InitialValue);
	__HAL_TIM_SetCompare(&Servo5_TIM, Servo5_Channel, InitialValue);
	__HAL_TIM_SetCompare(&Servo6_TIM, Servo6_Channel, InitialValue);
}

void SetServoAngle2PWM(float angle, uint8_t servonum)
{
	int16_t arr = 0;
	switch (servonum) {
		case 0 : arr = __HAL_TIM_GetAutoreload(&Servo1_TIM); break;
		case 1 : arr = __HAL_TIM_GetAutoreload(&Servo2_TIM); break;
		case 2 : arr = __HAL_TIM_GetAutoreload(&Servo3_TIM); break;
		case 3 : arr = __HAL_TIM_GetAutoreload(&Servo4_TIM); break;
		case 4 : arr = __HAL_TIM_GetAutoreload(&Servo5_TIM); break;
		case 5 : arr = __HAL_TIM_GetAutoreload(&Servo6_TIM); break;
		default : break;
	}
	
//	float duty = (0.5f + angle / 90.0f) / 20.0f;
//	float ccr = (float)(arr) * duty + 1.0f;
	float ccr = (float)(arr) * ((0.5f + angle / 90.0f) / 20.0f) + 1.0f;
	
	switch (servonum) {
		case 0 : __HAL_TIM_SetCompare(&Servo1_TIM, Servo1_Channel, (uint16_t)(ccr)); break;
		case 1 : __HAL_TIM_SetCompare(&Servo2_TIM, Servo2_Channel, (uint16_t)(ccr)); break;
		case 2 : __HAL_TIM_SetCompare(&Servo3_TIM, Servo3_Channel, (uint16_t)(ccr)); break;
		case 3 : __HAL_TIM_SetCompare(&Servo4_TIM, Servo4_Channel, (uint16_t)(ccr)); break;
		case 4 : __HAL_TIM_SetCompare(&Servo5_TIM, Servo5_Channel, (uint16_t)(ccr)); break;
		case 5 : __HAL_TIM_SetCompare(&Servo6_TIM, Servo6_Channel, (uint16_t)(ccr)); break;
		default : break;
	}
}

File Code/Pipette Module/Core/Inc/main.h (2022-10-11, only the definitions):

#define LED_Pin GPIO_PIN_13
#define LED_GPIO_Port GPIOC
#define MOTOR_IN1_Pin GPIO_PIN_4
#define MOTOR_IN1_GPIO_Port GPIOA
#define MOTOR_IN2_Pin GPIO_PIN_5
#define MOTOR_IN2_GPIO_Port GPIOA
#define MOTOR_IN3_Pin GPIO_PIN_6
#define MOTOR_IN3_GPIO_Port GPIOA
#define MOTOR_IN4_Pin GPIO_PIN_7
#define MOTOR_IN4_GPIO_Port GPIOA
#define SG_PRESS_Pin GPIO_PIN_8
#define SG_PRESS_GPIO_Port GPIOA
#define SG_ROTATE_Pin GPIO_PIN_9
#define SG_ROTATE_GPIO_Port GPIOA
#define KEY_Pin GPIO_PIN_9
#define KEY_GPIO_Port GPIOB
#define KEY_EXTI_IRQn EXTI9_5_IRQn

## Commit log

2022-10-11 Update directory structure.
    [Pipette Module.STL]
2022-10-12 Update frame module code.
    [Configuration.h, Configuration_adv.h]
2022-10-12 Update PCB project.
    [Core board.PrjPcb, Mainboard.PrjPcb, PCB1.PcbDoc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]
2022-10-12 Update model project.
    [1020铝型材_热床.SLDPRT, 1925联轴器8×5.SLDPRT, 2020铝型材_X轴.SLDPRT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]

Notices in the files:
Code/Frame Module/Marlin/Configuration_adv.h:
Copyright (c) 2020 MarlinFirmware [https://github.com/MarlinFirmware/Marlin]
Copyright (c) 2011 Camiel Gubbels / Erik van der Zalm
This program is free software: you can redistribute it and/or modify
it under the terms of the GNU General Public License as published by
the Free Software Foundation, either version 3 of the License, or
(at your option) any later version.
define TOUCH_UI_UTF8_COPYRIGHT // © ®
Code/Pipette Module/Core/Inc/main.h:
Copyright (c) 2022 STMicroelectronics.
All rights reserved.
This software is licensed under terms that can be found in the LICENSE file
